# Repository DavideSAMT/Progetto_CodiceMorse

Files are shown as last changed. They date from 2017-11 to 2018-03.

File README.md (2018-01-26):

# Progetto_CodiceMorse

## Diari
 - [I3_Diario_Prog2_2017_11_10](Documentazione/Diari/I3_Diario_Prog2_2017_11_10.pdf)
 - [I3_Diario_Prog2_2017_11_17](Documentazione/Diari/I3_Diario_Prog2_2017_11_17.pdf)
 - [I3_Diario_Prog2_2017_11_22](Documentazione/Diari/I3_Diario_Prog2_2017_11_22.pdf)
 - [I3_Diario_Prog2_2017_12_01](Documentazione/Diari/I3_Diario_Prog2_2017_12_01.pdf)
 - [I3_Diario_Prog2_2017_12_15](Documentazione/Diari/I3_Diario_Prog2_2017_12_15.pdf)
 - [I3_Diario_Prog2_2017_12_22](Documentazione/Diari/I3_Diario_Prog2_2017_12_22.pdf)
 - [I3_Diario_Prog2_2018_01_12](Documentazione/Diari/I3_Diario_Prog2_2018_01_12.pdf)
 - [I3_Diario_Prog2_2018_01_19](Documentazione/Diari/I3_Diario_Prog2_2018_01_19.pdf)
 - [I3_Diario_Prog2_2018_01_26](Documentazione/Diari/I3_Diario_Prog2_2018_01_26.pdf)

## Documentazione
 - [Documentazione](Documentazione/Documentazione.doc)

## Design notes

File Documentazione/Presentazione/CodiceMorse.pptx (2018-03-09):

## Codice Morse

Federico agosta, Alessandro gomes, davide paradiso
e Patrick sartori

## Indice

- Analisi
- Progettazione
- Implementazione
- Test
- Conclusione

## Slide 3

Analisi

## Analisi – richiesta del mandante

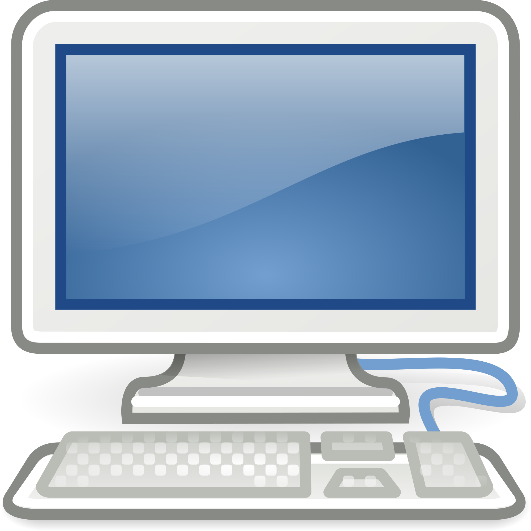
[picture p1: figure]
Risultati immagini per computer
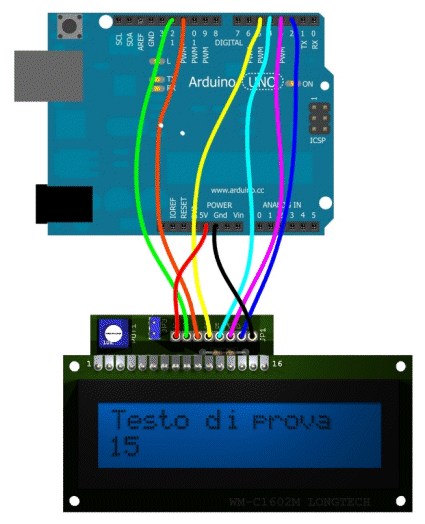
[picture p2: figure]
Risultati immagini per lcd

## Analisi – costi

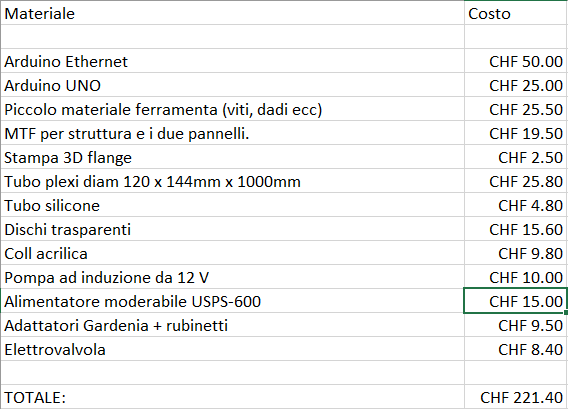
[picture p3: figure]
Analisi costi

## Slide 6

Progettazione

## Progettazione

Inserimento testo
Codifica
Salvataggio database, invio codice ad arduino
Azionamento elettrovalvola
Lettura frequenta e stampa su LCD

Bootstrap

PHP e JS

PHP

Arduino

## Progettazione pagina iniziale

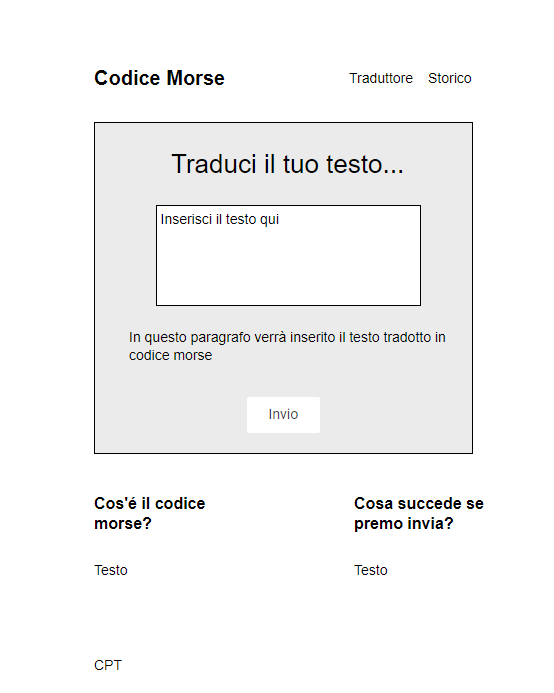
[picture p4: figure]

## Progettazione pagina storico

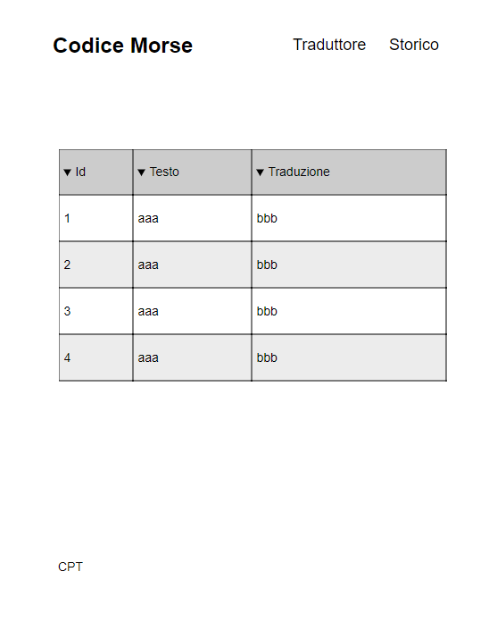
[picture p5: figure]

## Progettazione - database

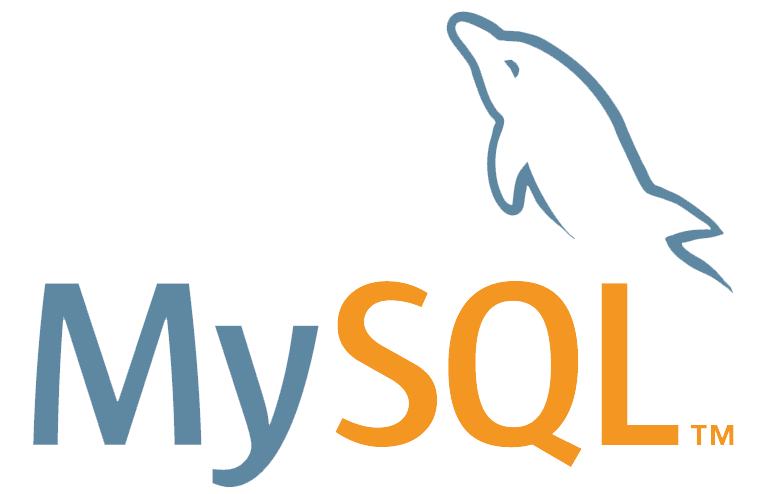
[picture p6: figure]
Risultati immagini per mysql
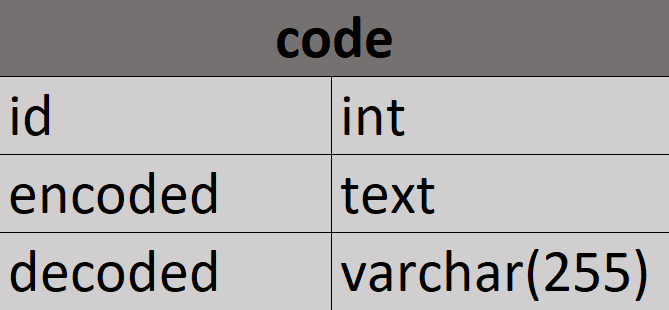
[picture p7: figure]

## Progettazione - elettrovalvola

- x1
- x3
- x7

## Progettazione - elettrovalvola

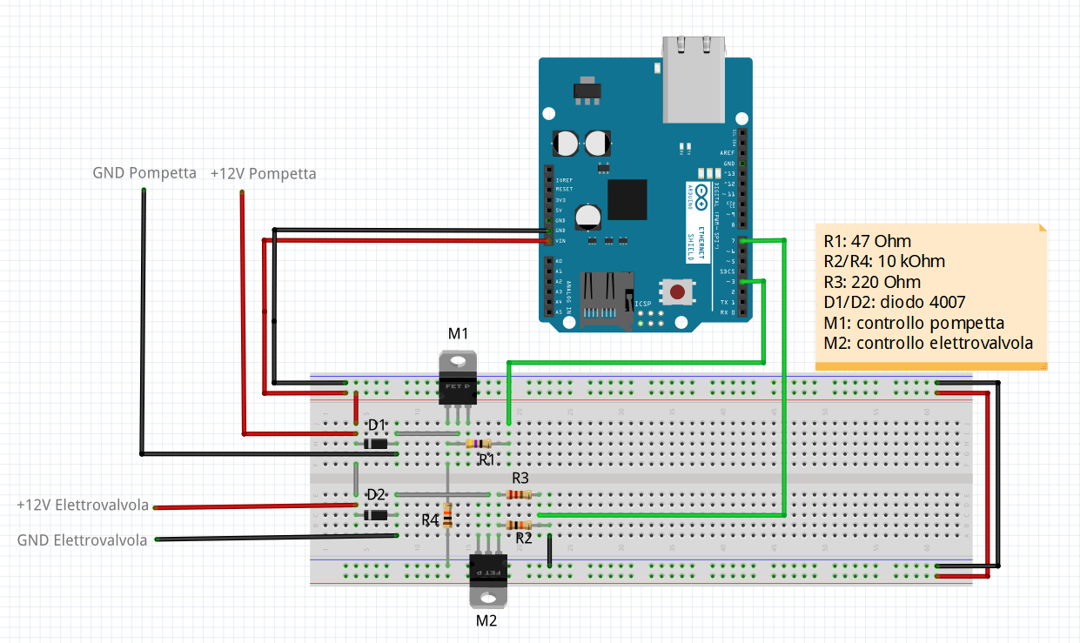
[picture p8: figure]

## Progettazione – sensore infrarossi

D

E

D

E

0

1

## Progettazione – sensore infrarossi

DOT

D

E

D

E

0

1

DASH

1111

1111111

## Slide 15

Il sensore legge un livello d’acqua insufficiente

Il sensore legge un livello d’acqua sufficiente

La pompa viene attivata

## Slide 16

Messaggio
Codificato con
Le gocce

Arduino

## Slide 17

Implementazione

## Implementazione pagina iniziale

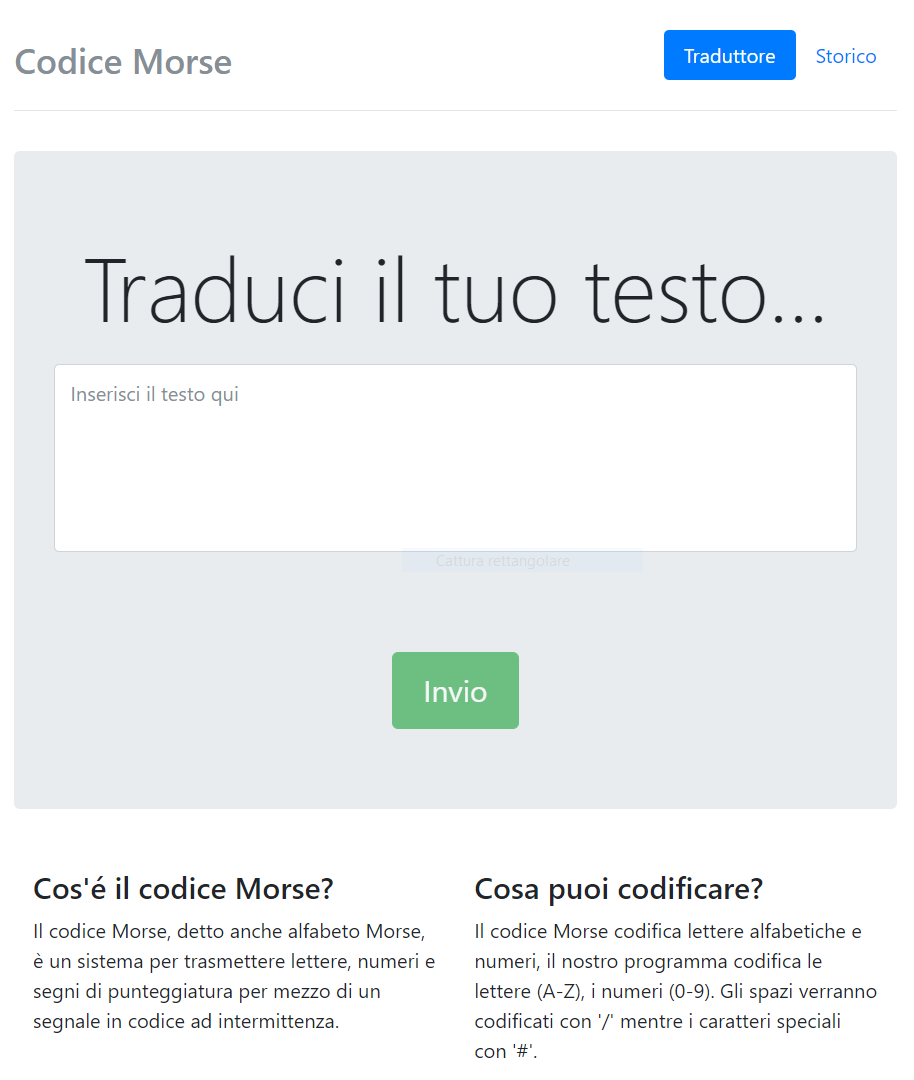
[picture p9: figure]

## Implementazione – pagina storico

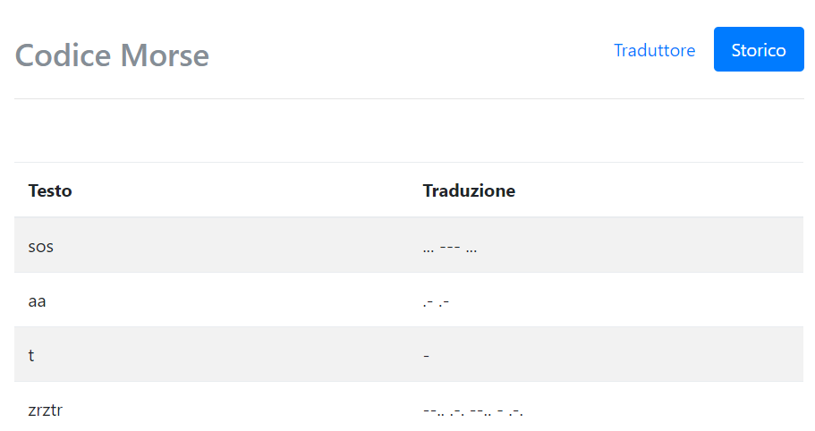
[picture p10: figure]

## Implementazione – pagina storico

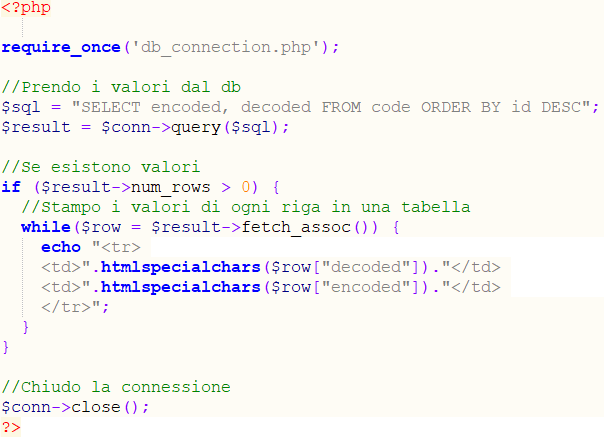
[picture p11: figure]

## Implementazione – controlli JS

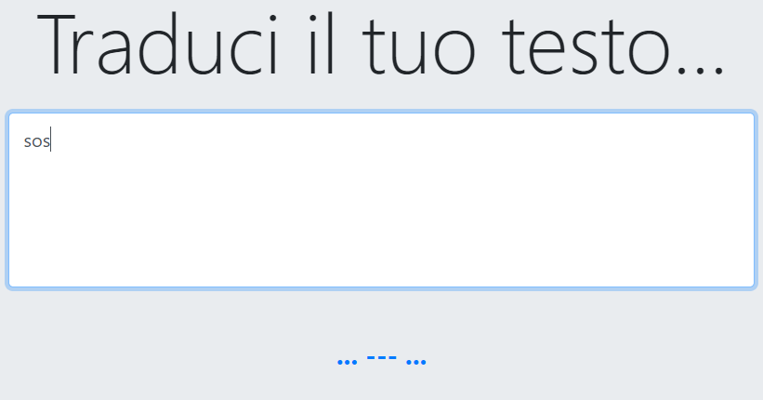
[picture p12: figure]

## Implementazione – controlli JS

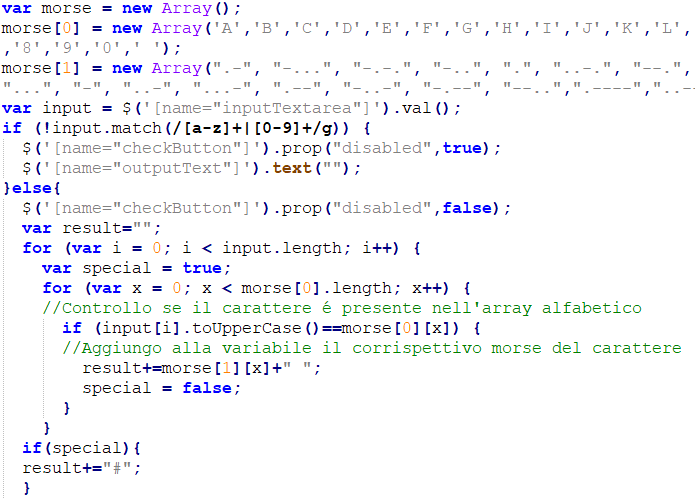
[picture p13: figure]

## Implementazione - elettrovalvola

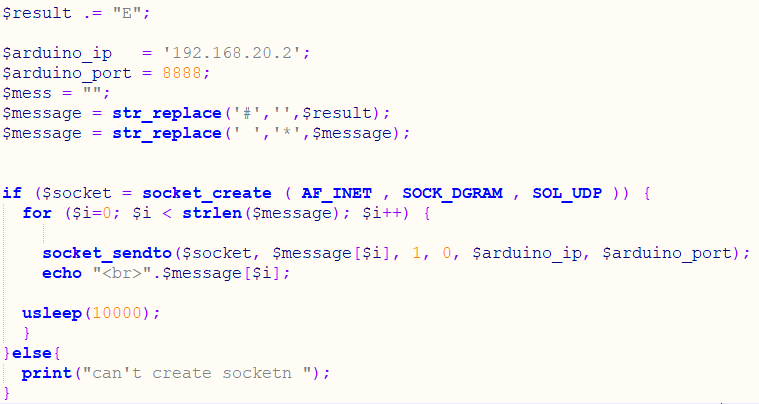
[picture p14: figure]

## Implementazione elettrovalvola

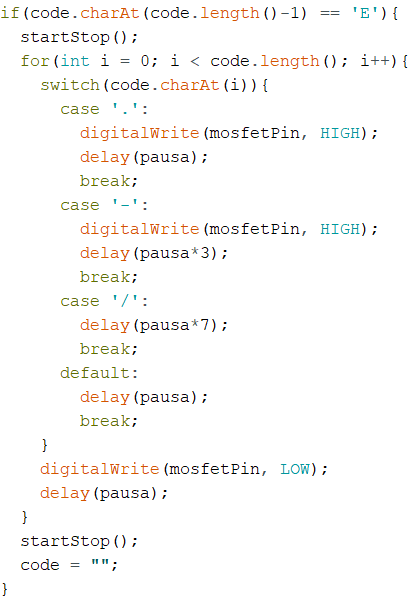
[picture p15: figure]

## Implementazione – pompetta e sensore

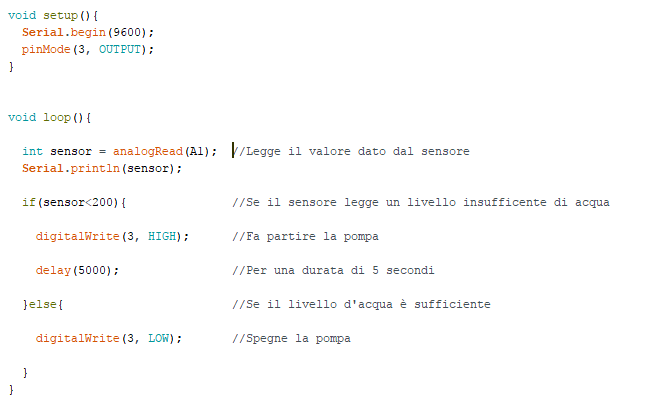
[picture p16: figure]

## Implementazione infrarossi

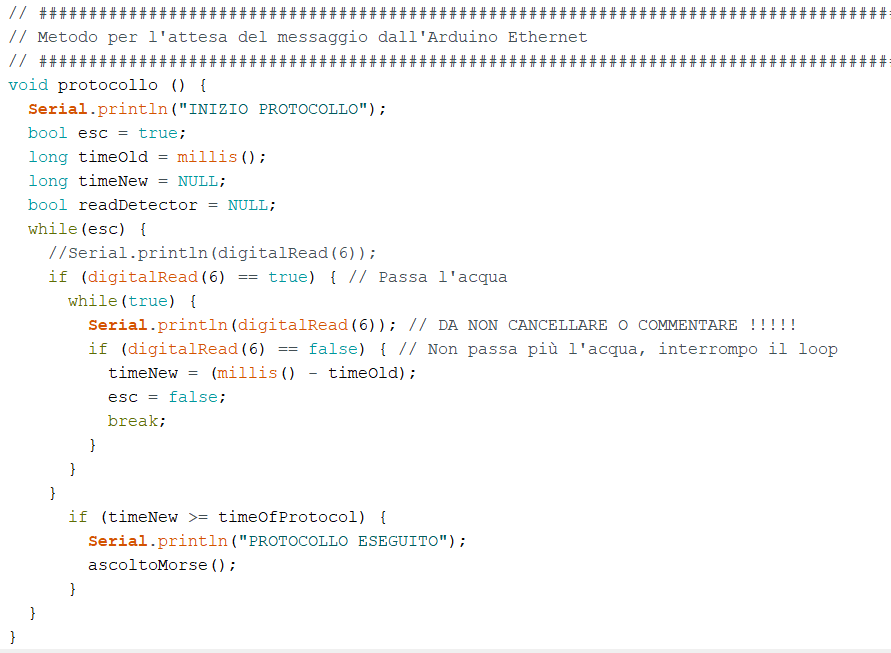
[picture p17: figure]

## Implementazione – sensore infrarossi

Goccia

No goccia

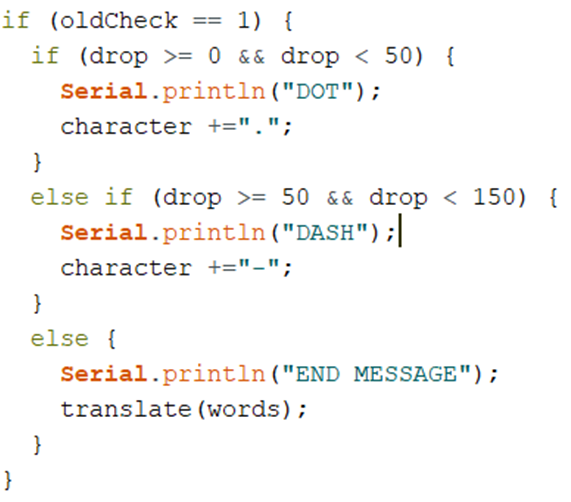
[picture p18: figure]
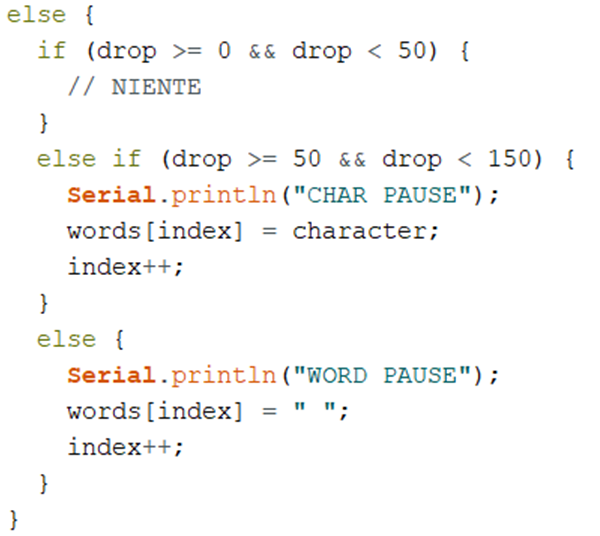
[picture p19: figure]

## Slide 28

Test

## Test

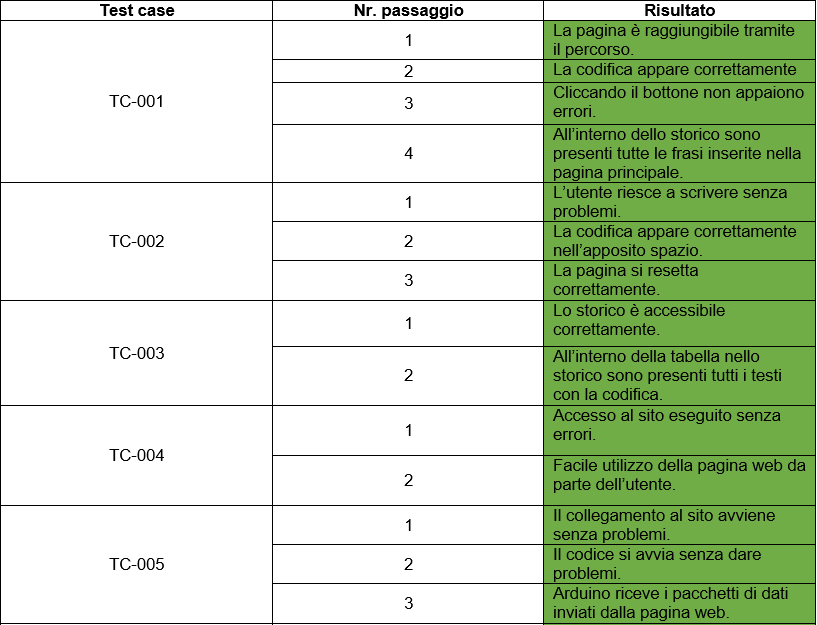
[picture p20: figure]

## Test

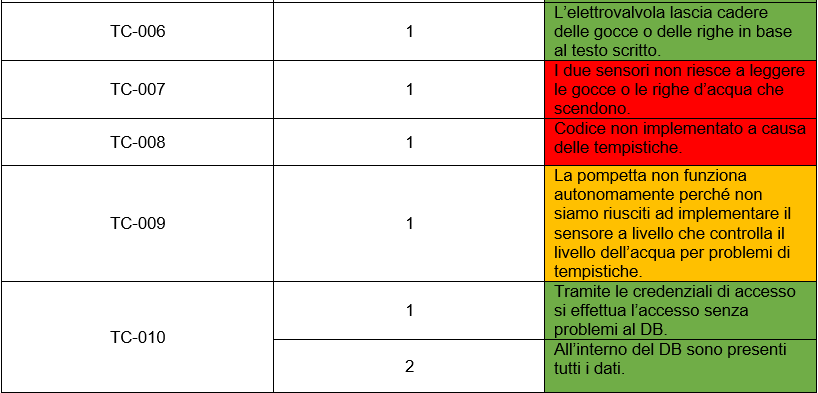
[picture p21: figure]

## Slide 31

Conclusioni

## Conclusioni

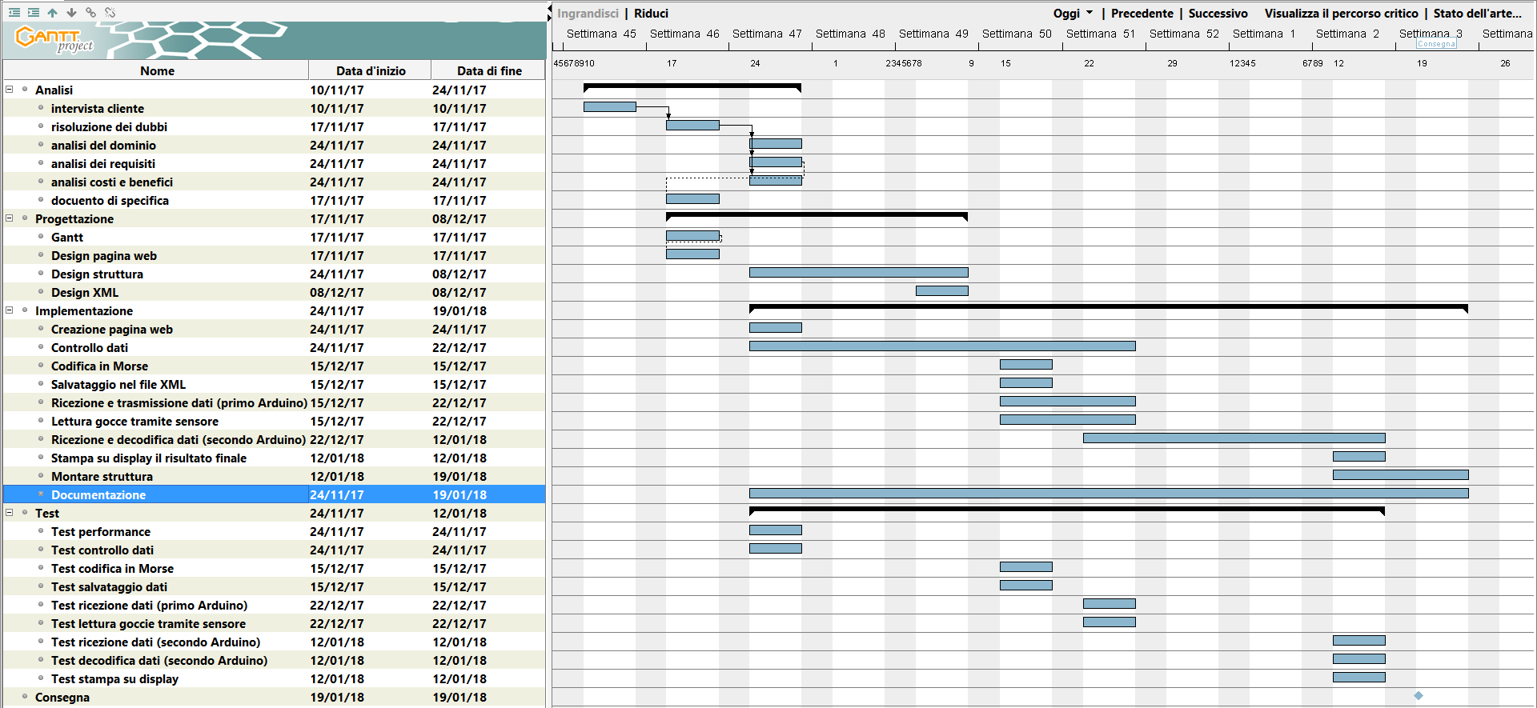
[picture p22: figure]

## Conclusioni

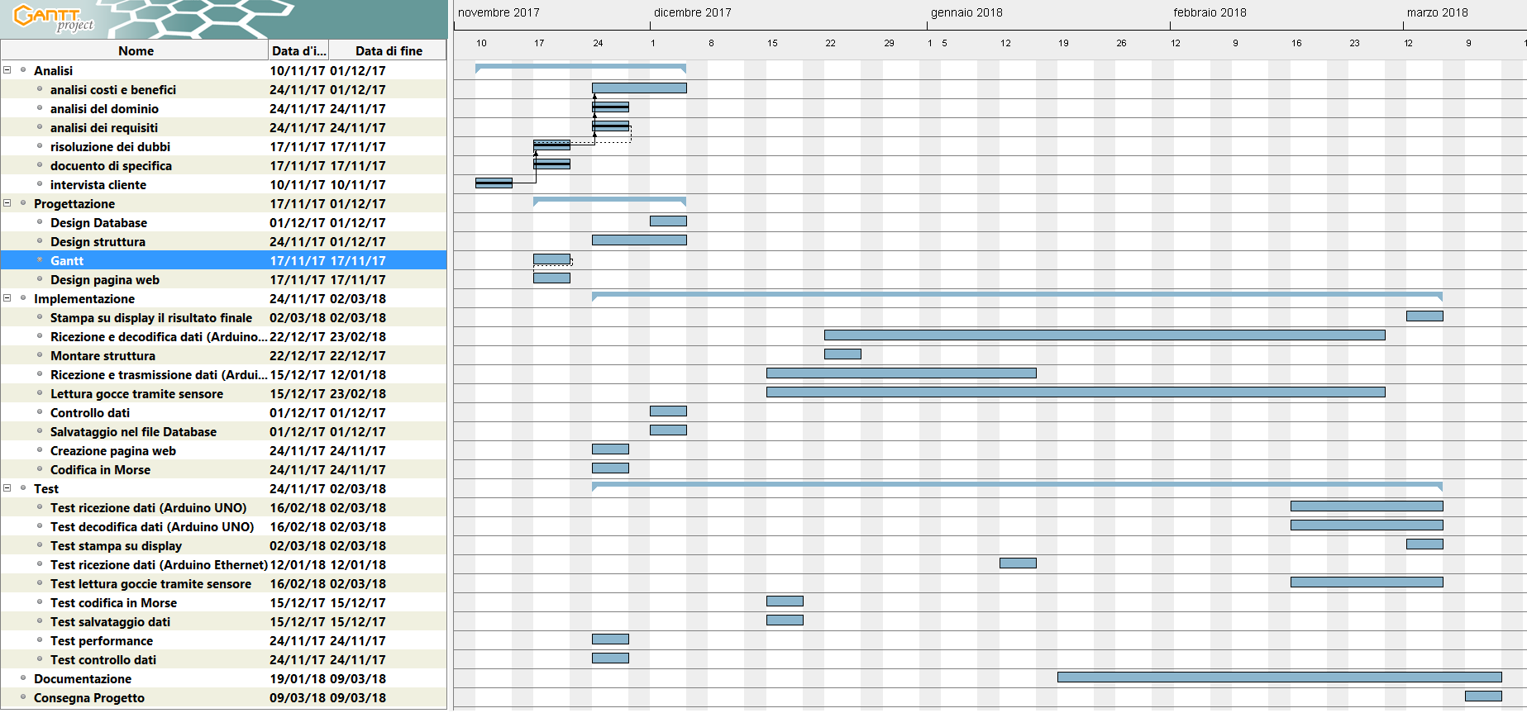
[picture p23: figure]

## Sviluppi futuri

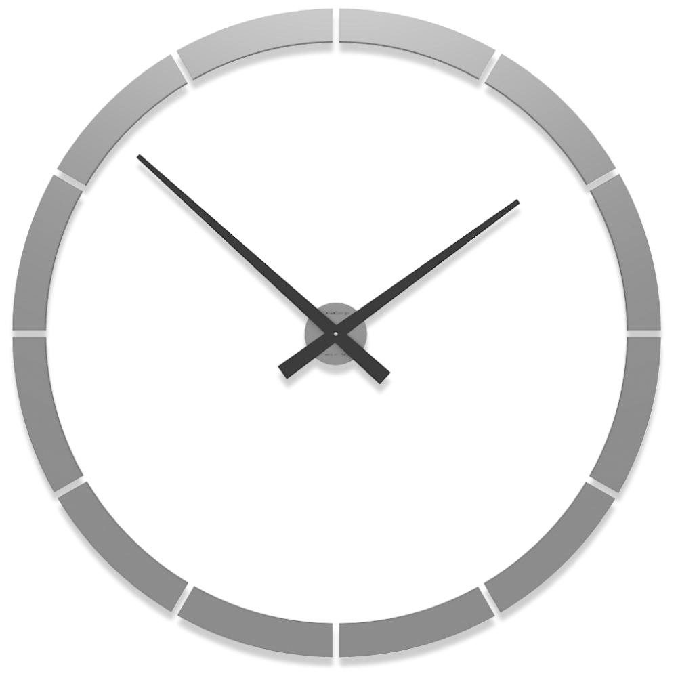
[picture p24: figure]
Risultati immagini per orologio

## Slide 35

Domande ?

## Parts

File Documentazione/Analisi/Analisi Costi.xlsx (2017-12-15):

Quantità | Materiale | Costo | Sito | ID
2 | Arduino/Genuino UNO | CHF 30.00
4 | Squadretta di fissaggio | CHF 5.55 | shop-da.dkh.ch | 10249209
16 | Viti per il legno 0.4 cm diametro | CHF 5.20
2 | Compensato 100 cm x 100 cm spessore 2.5 cm

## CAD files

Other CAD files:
Codice/ProgettoGraficoDavide.skp

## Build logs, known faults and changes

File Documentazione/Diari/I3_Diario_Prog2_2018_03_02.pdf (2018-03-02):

Davide Paradiso, Patrick Sartori, Alessandro Gomes

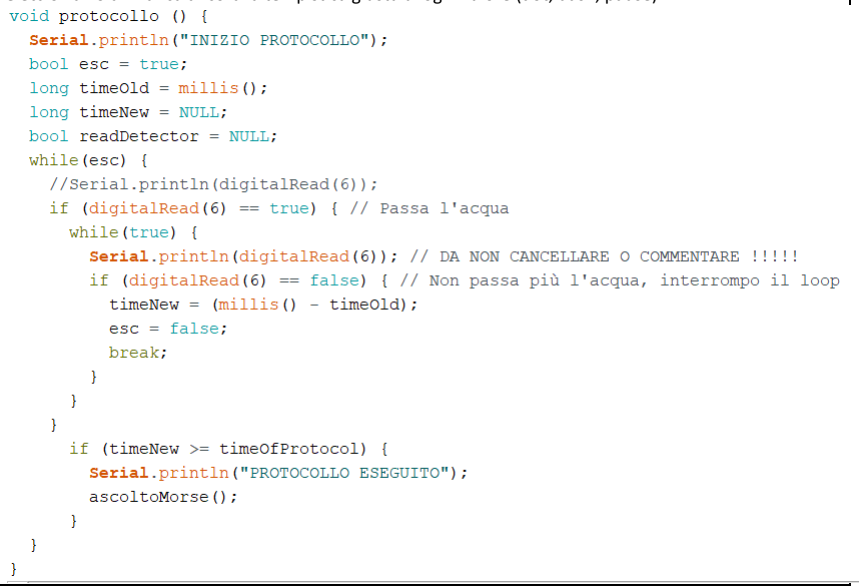
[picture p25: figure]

Nome Progetto: Codice Morse | 1/1

# Diario di lavoro

Luogo | Scuola Arti e Mestieri Trevano
Data | 02.03.18

Lavori svolti
Davide Paradiso:
Sono riuscito a concludere il codice sorgente della trasmissione a infrarossi abbastanza per testare con la elettro valvola. Manca ancora la tempistica giusta di ogni valore (dot, dash, pause).

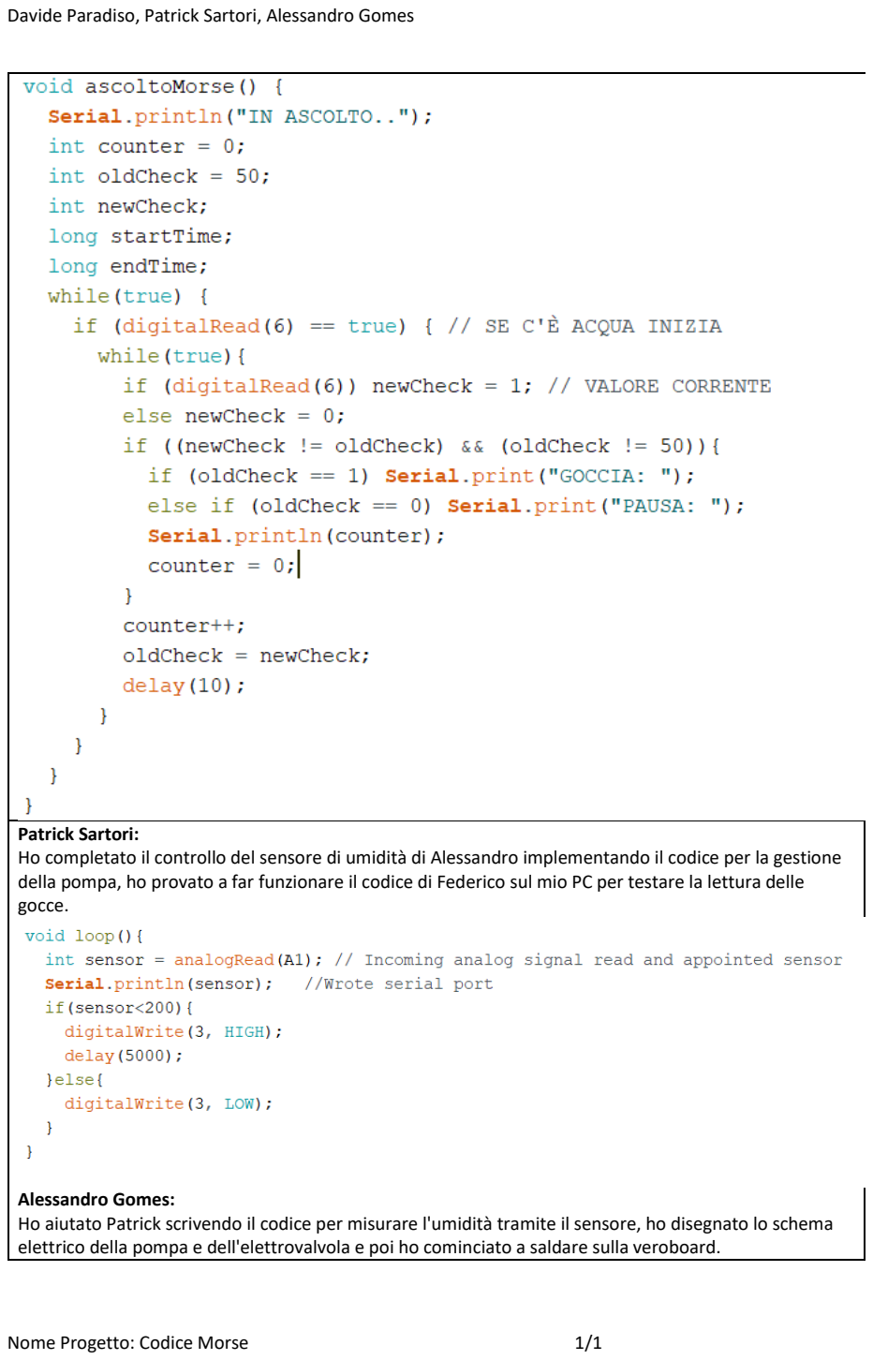
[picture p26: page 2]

Patrick Sartori:
Ho completato il controllo del sensore di umidità di Alessandro implementando il codice per la gestione della pompa, ho provato a far funzionare il codice di Federico sul mio PC per testare la lettura delle gocce.

Alessandro Gomes:
Ho aiutato Patrick scrivendo il codice per misurare l'umidità tramite il sensore, ho disegnato lo schema elettrico della pompa e dell'elettrovalvola e poi ho cominciato a saldare sulla veroboard.

Problemi riscontrati e soluzioni adottate
Davide Paradiso:
Ho riscontrato problemi con il codice sorgente ma grazie all’aiuto del professor Barchi sono riuscito a risolvere. Purtroppo non ho potuto testare perché la parte dell’elettro valvola che settimana scorsa andava, oggi sul pc di Patrick e sul mio non ha funzionato, abbiamo chiamato Federico al telefono svariate volte ma lui ha confermato che i codici erano giusti e il montaggio anche.
Patrick Sartori:
Non riuscivo a creare il socket, ho dovuto abilitare l'estensione per i socket in php.ini.
Alessandro Gomes:
Devo dissaldare una resistenza il PULL_DOWN perché l’ho messa male.

Punto della situazione rispetto alla pianificazione Progetto non concluso.

Programma di massima per la prossima giornata di lavoro

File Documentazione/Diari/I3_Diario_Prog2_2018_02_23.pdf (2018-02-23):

Davide Paradiso, Patrick Sartori, Federico Agosta, Alessandro Gomes

Progetto codice morse | 1/1

# Diario di lavoro

Luogo | SAMT
Data | 23.02.2018

Lavori svolti

Ho messo in rete la macchina con arduino sulla rete 200.200.200.1, poi ho eseguito una modifica del db e della query di creazione della struttura
perché ci siamo accorti che il range di varchar non basta per contenere la stringa di 255 caratteri codificata.
Invece di inviare spazi vuoti tra carattere e carattere ho introdotto il carattere * (Es: SOS -> ...*---*...*E), inoltre ho tolto lo switch
che controllava il tempo da PHP (pagina data_backup.php) perché lo gestisce Arduino (valvola.ino).
Ho aggiunto il codice Arduino che gestisce l'elettrovalvola collegata alla pagina PHP, in modo che quando viene inviato un messaggio l'elettrovalvola
stampa il risultato in codice morse corretto e con le tempistiche giuste, in caso che si invii un nuovo messaggio durante l'elaborazione il messaggio verrà
archiviato e eseguito appena possibile.

Oggi sono riuscito a far funzionare la pompa, i problemi erano:
Il mosfet danneggiato,
Gli ingranaggi non oliati,
La resistenza di controllo del mosfet era troppo alta.

Problemi riscontrati e soluzioni adottate

Ho sostituito il mosfet,

Ho oliato gli ingranaggi del motore,

Ho sostituito la resisteza di controllo con una resistenza da 47 Ohm.

Programma di massima per la prossima giornata di lavoro

La prossima lezione devo controllare che la query funzioni e controllare la riga 64 di valvola.ino se é superflua o meno.

Davide Paradiso, Patrick Sartori, Federico Agosta, Alessandro Gomes

Progetto codice morse | 1/1

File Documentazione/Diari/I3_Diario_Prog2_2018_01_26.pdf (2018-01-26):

Davide Paradiso, Patrick Sartori, Federico Agosta, Alessandro Gomes

# Diario di lavoro

Luogo | SAMT
Data | 26.01.2018

Lavori svolti

Inizialmente abbiamo sistemato la struttura delle cartelle su github e aggiunto le informazione all'interno del readme.md iniziale.
Successivamente abbiamo dovuto modificare il codice della valvola di arduino in modo che sia arduino a gestire i tempi di attesa tra un punto e l'altro e non php, abbiamo dovuto di
conseguenza modificare anche il codice di php che gestiva il tempo, inoltre abbiamo aggiunto un carattere "E" per segnalare la fine del messaggio in modo che dopo
arduino possa ripulire la variabile. Una volta terminato il lavoro abbiamo cominciato con il testare la elettro valvola per poterla implementare
all'interno del codice di arduino "valvola.ino", dato che il voltaggio del arduino é troppo debole per poter alimentare l'elettro valvola
ci è stato dato un Mosfet "IRF520" che può distribuire fino a 100V e 9,2A, per l'elettro valvola basta un voltaggio di 12V e 250mA.
Le informazioni le abbiamo prese da "https://www.vishay.com/docs/91017/91017.pdf".
Inoltre abbiamo cominciato il montaggio della struttura con le misure corrette e il materiale adeguato, prima di cominciare abbiamo ottenuto l’accordo da parte dei docenti responsabili dato che non abbiamo cambi in caso di errore.

Problemi riscontrati e soluzioni adottate

Capire come funziona il Mosfet e riuscire a tesarlo insieme all’ elettro valvola in modo che funzionasse. Per il montaggio bisognava aspettare il docente responsabile che supervisionasse che non sempre era disponibile.

Punto della situazione rispetto alla pianificazione

In confronto alla pianificazione avremmo già dovuto finire, ma se la consegna è espoprofessioni siamo a buon punto.

Programma di massima per la prossima giornata di lavoro

Terminare il funzionamento dell’elettro valvola funzionante e terminare il montaggio rude della struttura (pittura e abbellimenti verranno effettuati in seguito). Poi ci rimarrà solamente da leggere le gocce e stampare sul display LCD.

Progetto codice morse | 1/1

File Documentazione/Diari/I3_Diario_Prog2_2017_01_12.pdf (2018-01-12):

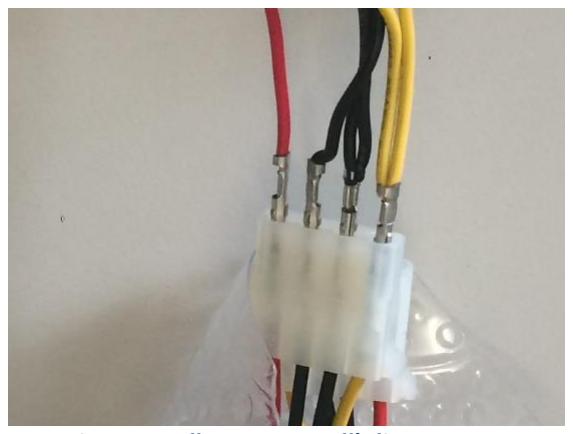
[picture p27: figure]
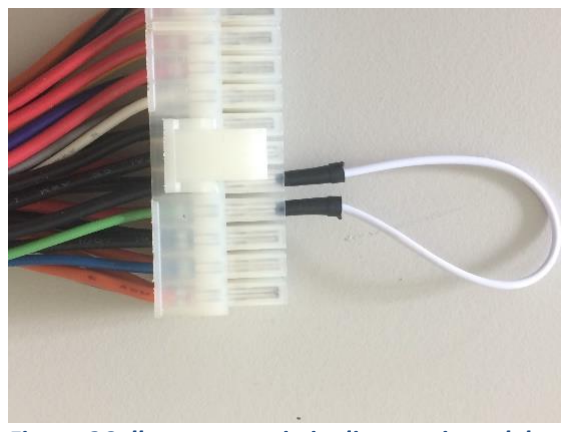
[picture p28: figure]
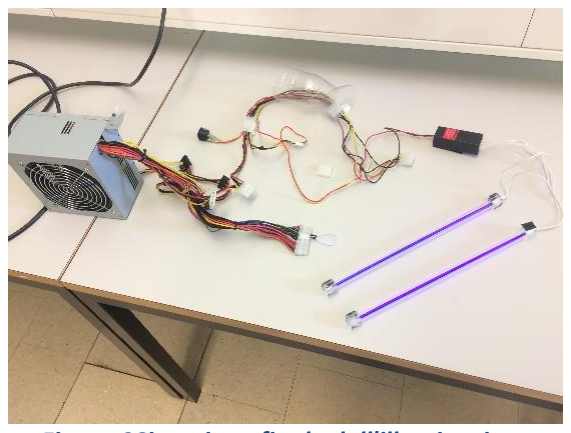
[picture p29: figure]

Nome Progetto: Codice Morse | 1/1

# Diario di lavoro

Luogo | Scuola Arti e Mestieri Trevano
Data | 12.01.2018

Lavori svolti
Davide:
A inizio lezione ho preso le misure per il fissaggio dei componenti sull’infrastruttura. Prima di pranzo ho fatto funzionare il sistema di illuminazione per l’acqua.

Figura 1Collegamento all'alimentatore

Figura 2Collegamento ai pin di accensione del pc

Figura 3Situazione finale dell'illuminazione

Dopo pranzo ho iniziato a simulare la comunicazione tra due arduini e l’invio di un codice morse.

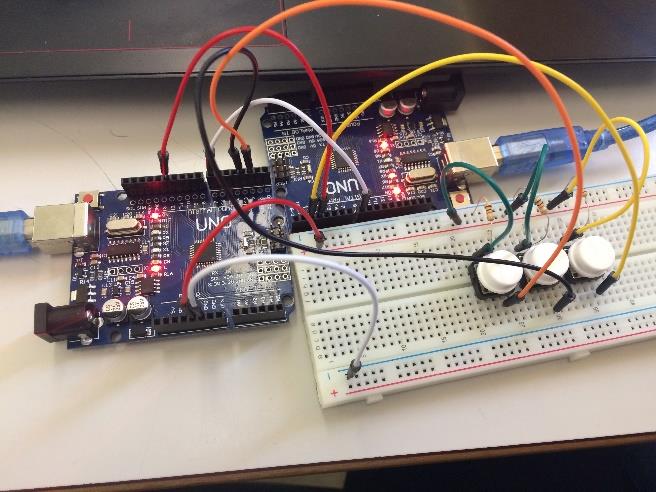
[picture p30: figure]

L’immagine seguente è il codice dell’Arduino che simula la scrittura del morse e manda il messaggio al secondo Arduino.

Federico:

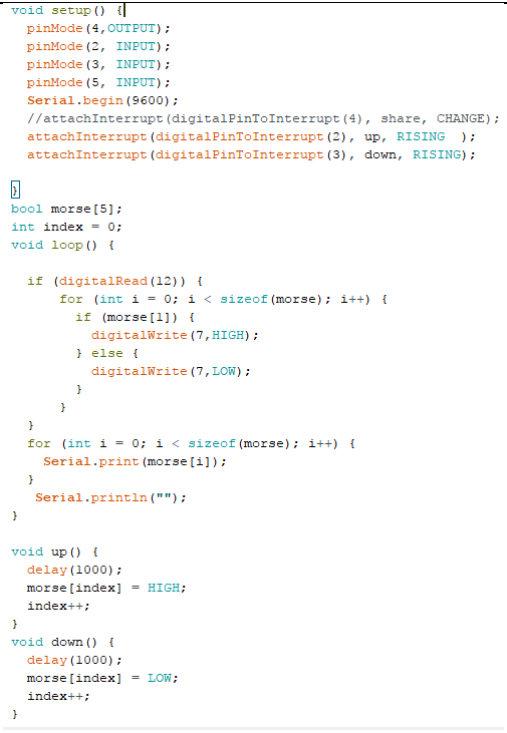
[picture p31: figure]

Ho cercato un metodo per inviare i dati da PHP a d Arduino, ho trovato un sistema che potrebbe fare al caso nostro all'indirizzo https://www.arduino.cc/en/Tutorial/UDPSendReceiveString
usando UDPSendReceiveString di é possibile tenere Arduino in ascolto su una porta a nostra scelta, per poter testare se funziona abbiamo bisogno della libreria EthernetUdp.h di Arduino.
Nelle impostazioni di php.ini ho dovuto abilitare i socket di php, l'inforamzione l'ho trovata grazie all'errore https://stackoverflow.com/questions/6137823/fatal-error-call-to-undefined-function-socket-create
Una volta inviati i dati abbiamo dovuto aumentare il tempo di esecuzione da php.ini, ho deciso di inviare un carattere alla volta per poter rispettare il massimo di 24byte massimi del protocollo udp e con lo sleep si può fare in modo di aprire e chiudere direttamente la elettro valvola. Per poter aggiungere tesmpo ho aggiunto
$cfg['ExecTimeLimit'] = 6000; in config.inc.php e max_execution_time in php.ini.

Patrick:
Durante questa lezione mi sono occupato di creare il codice di arduino per leggere il codice inviato tramite dei bottoni.

void setup() {
pinMode(8, INPUT);
pinMode(2, INPUT);
Serial.begin(9600);
attachInterrupt(digitalPinToInterrupt(2), invio,RISING);

}
bool ciao[5];
void invio(){
digitalWrite(3, HIGH);
for(int i =0;i<sizeof(ciao); i++){ ciao[i] = digitalRead(8);
}
}

String s1;
void loop() {
//s1=ciao[0]+ciao[1]+ciao[2]+ciao[3]+ciao[4]; for(int i =0;i<sizeof(ciao); i++){
delay(5);
Serial.print(ciao[i]);
}

/* String morse[] = {".-", "-...", "-.-.", "-..", ".", "..-.", "--.", "....", "..", ".---", "-.-", ".-..", "--", "-.", "---", ".--.", "--.-", ".-.", "...", "-", "..-", "...-", ".--", "-..-", "-.--", "--..",".----","..---","...--","....-",".....","-....","--...","---..","----.","-----", "/"};
char
alfa[]={'A','B','C','D','E','F','G','H','I','J','K','L','M','N','O','P','Q','R','S','T','U','V','W','X','Y','Z','1','2','3','4','5','6',' 7','8','9','0',' '};
for(int i = 0; i<sizeof(morse);i++){
if(s1==morse[i]){
s1=alfa[i];
}
}
for(int i = 0; i<sizeof(morse);i++){ if(s2==morse[i]){
s2=alfa[i];
}
}
for(int i = 0; i<sizeof(morse);i++){ if(s3==morse[i]){
s3=alfa[i];
}

}*/
Serial.println();
}

Problemi riscontrati e soluzioni adottate
I due Arduini leggono e scrivono troppo velocemente e anche avendo usato gli interrupt non sono sincronizzati.
Purtroppo il problema persiste ancora.
Il codice legge solo i codici “…..” (“11111”) e “-----” (“00000”), non abbiamo trovato una soluzione ma abbiamo delle supposizioni ovvero:
1. O l’arduino che invia manda il messaggio troppo velocemente oppure l’arduino che riceve legge il messaggio troppo velocemente.
Viene considerato il primo indice dell’array e viene stampato solo quello.

Punto della situazione rispetto alla pianificazione In ritardo rispetto alla pianificazione iniziale

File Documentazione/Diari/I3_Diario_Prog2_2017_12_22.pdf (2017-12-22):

Federico Agosta, Alessandro Gomes, Davide Paradiso e Patrick Sartori

# Diario di lavoro

Luogo | Scuola Arti e Mestieri Trevano
Data | 22.12.2017

Lavori svolti
Federico Agosta:
Ho cambiato l’IP del mio computer che lo usiamo come server in 200.200.200.1 (ip statico), poi ho rimosso il proxy e attivato xampp, in questo modo il computer è pronto per lavorare.
Appena cominciato a lavorare si è risolto da solo il problema della connessione tra arduino e il nostro server, probabilmente la soluzione è stata nello spegnere e riaccendere il pc.
Poi abbiamo cominciato ad informarci su come inviare delle variabili da PHP ad arduino dato che le nostre conoscenze su questi linguaggi sono scarse. Abbiamo usufruito della guida ufficiale di arduino per capire meglio il funzionamento del prodotto, soprattutto su come utilizzare i socket.
Ho cominciato a fare dei test per capire e verificare il funzionamento dei socket dato che non gli ho mai utilizzati.
Ho preso il codice da arduino.cc per fare in modo che il nostro ArduinoEthernet sia in ascolto su una porta e riceva dei messaggi.

Alessandro Gomes:
Ho rimosso il proxy perché la scuola ha problemi con la rete e di conseguenza mi sono dovuto collegare alla mia rete internet personale tramite il mio telefono.
Subito dopo ho cominciato a fare ricerche per aiutare il mio compagno Federico a risolvere il problema del collegamento tra l’arduino e il computer, una volta risolto ho cominciato a fare altre ricerche per aiutare il mio collega di progetto nel collegamento tra l’arduino e la pagine web. In seguito ho dovuto modificare diversi capitoli della documentazione e anche aggiungere nel Gantt il tempo per la documentazione.

Davide Paradiso:
Ho fatto diverse prova per la lettura delle gocce, sia con il lettore d’infrarossi che con il lettore laser. Alla fine per motivi organizzativi e per ordine del sore ho insistito con la lettura tramite infrarossi. Il lettore laser era troppo impreciso e al minimo spostamento non leggeva più il segnale.
La versione finale del codice sorgente che sto utilizzando è il seguente:

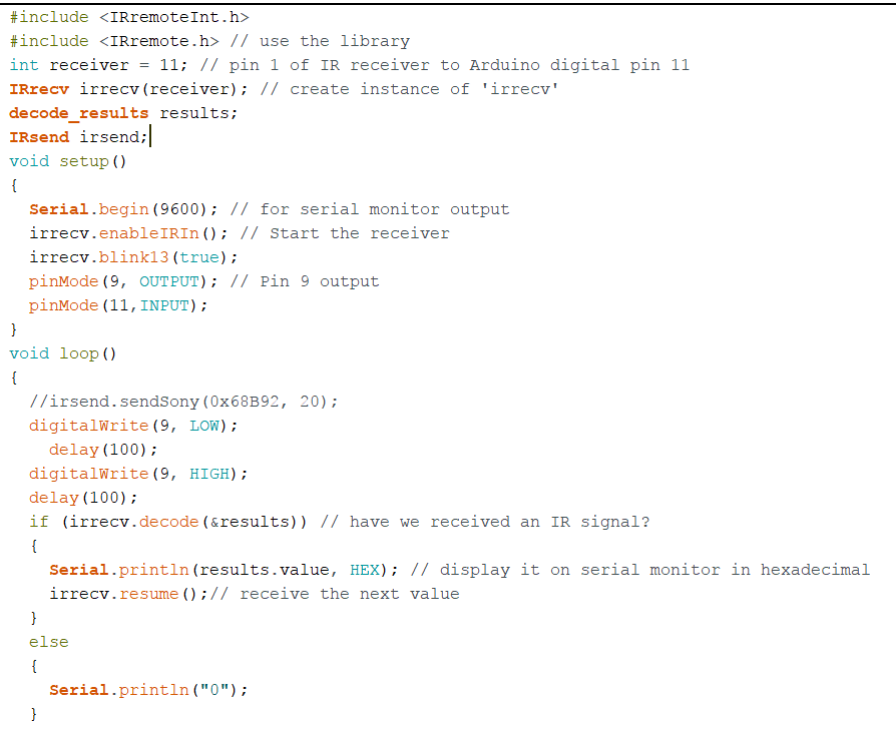
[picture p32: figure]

Appena saprò con certezza i pezzi giusti da usare pubblicherò i loro data sheets su GitHub.

Patrick Sartori:
Ho aggiornato il gantt consuntivo, ho cercato il modello del led a infrarossi per poi cercare il datasheet, il modello di led a infrarossi che usiamo è lo TSUS 5402.

Problemi riscontrati e soluzioni adottate
Alle 10.20 abbiamo avuto bisogno di internet ma la rete scolastica non funzionava, abbiamo dovuto attendere che risolvessero il problema, intento abbiamo usato il nostro internet fornito dai telefoni cellulari.
L’attuatore ad infrarossi non ha la stessa frequenza del sensore di lettura, l’ho verificato leggendo i data sheets di entrambi i pezzi, quindi poi ho cercato un attuatore compatibile.
Essendo che il nostro attuatore e il nostro ricevitore non sono compatibili ho cercato un altro attuatore compatibile e l’attuatore che ho trovato è l’IR333-A, sito del datasheet: https://docs.particle.io/assets/datasheets/makerkit/ir333-a.pdf

Punto della situazione rispetto alla pianificazione Leggermente indietro confronto alla pianificazione

Programma di massima per la prossima giornata di lavoro
Per le vacanze devo trovare una soluzione e comunicarla al sore. (Davide)

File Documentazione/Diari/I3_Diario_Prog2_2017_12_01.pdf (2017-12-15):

Davide Paradiso, Patrick Sartori, Federico Agosta, Alessandro Gomes

Progetto codice morse | 1/1

# Diario di lavoro

Luogo | SAMT
Data | 1.12.2017

Lavori svolti

Oggi abbiamo iniziato a fare l’analisi dei costi, abbiamo finito il file php per creare lo storico dei messaggi, abbiamo completato l’abstract, abbiamo iniziato a vedere come funzionano il led a infrarossi e il ricevitore a infrarossi, abbiamo provato a connettere l’arduino alla pagina web tramite un cavo ethernet, abbiamo aggiornato il gantt perché ci siamo dimenticati di includere il ponte, abbiamo bloccato la possibilità di ispezionare gli elementi in HTML e infine abbiamo finito lo schema grafico della struttura.

Problemi riscontrati e soluzioni adottate

Non siamo riusciti a trovare un cavo d’alimentazione per l’arduino, non riuscivamo a trovare il driver giusto per arduino, lo abbiamo risolto trovando il driver CH341SER, abbiamo avuto infine un ultimo problema con la formattazione del testo nelle tabelle che abbiamo poi risolto con il css usando nel tag table lo style=”table-layout:fixed”, e per il td lo sstyle=”word-wrap:break-word”.

Punto della situazione rispetto alla pianificazione

Siamo leggermente in anticipo.

Programma di massima per la prossima giornata di lavoro

Iniziare a programmare in arduino.
Modifica requisiti,

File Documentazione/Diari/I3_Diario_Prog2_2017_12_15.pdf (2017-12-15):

Davide Paradiso, Patrick Sartori, Federico Agosta, Alessandro Gomes

Progetto codice morse | 1/1

# Diario di lavoro

Luogo | SAMT
Data | 15.12.2017

Lavori svolti

Oggi abbiamo iniziato a programmare in arduino, siamo riusciti a far funzionare il ricevitore a infrarossi, stiamo iniziando a mandare i dati dalla pagina php all’arduino, abbiamo quasi ultimato l’analisi dei costi, abbiamo trovato e risolto un errore nel salvataggio dei dati nella tabella.

Problemi riscontrati e soluzioni adottate

Abbiamo riscontrato problemi con le librerie a infrarossi di arduino, con il led a infrarossi, con la connessione di arduino ethernet al computer.

Abbiamo risolto i problemi di libreria scaricando la stessa libreria di nuovo e i problemi di connessione di arduino ethernet cambiando l’adattatore ad arduino.

Punto della situazione rispetto alla pianificazione

Siamo in orario.

Programma di massima per la prossima giornata di lavoro

Finire la programmazione in arduino.
Far funzionare la lan di arduino.

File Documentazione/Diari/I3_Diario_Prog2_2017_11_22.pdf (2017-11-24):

Davide Paradiso, Patrick Sartori, Federico Agosta, Alessandro Gomes

Nome Progetto: Form di inserimento dati Espoprofessioni | 1/1

# Diario di lavoro

Luogo | Scuola Arti e Mestieri Trevano
Data | 24.11.2017

Lavori svolti
Abbiamo concluso la parte di analisi a parte la sezione dei costi, l’abstract, il gantt preventivo, abbiamo iniziato a progettare la struttura e fare l’elenco dei materiali.
Abbiamo aggiornato la documentazione.
Design della pagina web concluso e lo script che traduce l’italiano in morse.

Problemi riscontrati e soluzioni adottate

Punto della situazione rispetto alla pianificazione Più o meno in orario.

Programma di massima per la prossima giornata di lavoro Finire PHP e iniziare con Arduino.

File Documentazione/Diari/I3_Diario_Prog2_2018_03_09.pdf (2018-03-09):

Davide Paradiso, Patrick Sartori, Federico Agosta, Alessandro Gomes

Progetto codice morse | 1/1

# Diario di lavoro

Luogo | SAMT
Data | 09.03.2018

Lavori svolti

Oggi ci siamo dedicati a fare la documentazione e la presentazione.

Problemi riscontrati e soluzioni adottate

Punto della situazione rispetto alla pianificazione

Programma di massima per la prossima giornata di lavoro

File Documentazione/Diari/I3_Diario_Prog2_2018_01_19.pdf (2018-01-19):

Davide Paradiso, Patrick Sartori, Federico Agosta, Alessandro Gomes

Progetto codice morse | 1/1

# Diario di lavoro

Luogo | SAMT
Data | 19.01.2018

Lavori svolti

Durante la lezione di oggi ci siamo divisi in due gruppi, uno gruppo che si occupava di fare la documentazione e un gruppo che si occupava di fare la presentazione.
Federico si è occupato di aggiornare il trello e di sistemare il codice di arduino ethernet, Davide ha cominciato ad utilizzare il display LCD, Alessandro e Patrick hanno fatto gli ultimi elementi della documentazione mancanti, ovvero l’implementazione, i test case, il consuntivo, le conclusioni e il gantt consuntivo.

Problemi riscontrati e soluzioni adottate

Punto della situazione rispetto alla pianificazione

Consegna

Programma di massima per la prossima giornata di lavoro

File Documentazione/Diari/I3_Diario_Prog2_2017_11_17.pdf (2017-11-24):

Nome Progetto: | 1/1

# Diario di lavoro

Luogo | SAM Trevano
Data | 17.11.2017

Lavori svolti
Abbiamo fatto il colloquio con il docente responsabile, nel quale abbiamo risolto i nostri dubbi legati al mandato. Abbiamo cominciato a scrivere i requisiti per poi dividerci i compiti. Con trello abbiamo cominciato a scrivere i requisiti per poi gestirli meglio. Abbiamo cominciato con la documentazione del progetto.

Problemi riscontrati e soluzioni adottate
Nessun problema riscontrato

Punto della situazione rispetto alla pianificazione Stiamo ancora pianificando

Programma di massima per la prossima giornata di lavoro

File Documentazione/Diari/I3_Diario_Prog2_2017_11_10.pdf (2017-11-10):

Davide Paradiso, Patrick Sartori, Federico Agosta, Alessandro Gomes

Nome Progetto: Form di inserimento dati Espoprofessioni | 1/1

# Diario di lavoro

Luogo | Scuola Arti e Mestieri Trevano
Data | 10.11.2017

Lavori svolti
Abbiamo creato la Repository del progetto su Github e abbiamo iniziato a fare l’analisi dei requisiti. Abbiamo guardato il progetto di riferimento per darci un idea su come verrà.

Problemi riscontrati e soluzioni adottate

Punto della situazione rispetto alla pianificazione Più o meno in orario.

Programma di massima per la prossima giornata di lavoro

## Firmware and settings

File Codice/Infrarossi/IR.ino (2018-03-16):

int X;
#define emitter 5
#define detector 6
#define tester 8
int timer1_counter;
// VARIABILI MORSE VALORI STANDARD
// *******************************
int dot = 1;
int symbolSpace = dot;
int dash = dot * 3;
int letterSpace = dash;
int wordSpace = dot * 7;
// *******************************
int timeOfProtocol = 10; // MILLI_SECONDI
void setup() {
  pinMode(emitter, OUTPUT);
  pinMode(detector, INPUT);
  Serial.begin(9600);
  
  //inizialize Timer
  noInterrupts();           // Disabilito tutti gli interrupts
  TCCR1A = 0;               // TCCR1A, costante già esistente in Arduino
  TCCR1B = 0;               // TCCR1B, costante già esistente in Arduino
  timer1_counter = 65534;   // timer1_counter, variabile che rappresenta la frequenza
  TCNT1 = timer1_counter;   // TCNT1, costante già esistente in Arduino
  TCCR1B |= (1 << CS12);
  TIMSK1 |= (1 << TOIE1);
  interrupts();             // Riattivo tutti gli interrupts
}
// Frequenza dell'emitter
bool frequencyE;
// Frequenza del detector
bool frequencyD;
ISR(TIMER1_OVF_vect) {
  TCNT1 = timer1_counter;
  // Imposto la frequenza dell'emitter IR
  digitalWrite(emitter, digitalRead(emitter) ^ 1);
  // EMITTER FREQUENCY
  frequencyE = (digitalRead(emitter) ^ 1);
  // DETECTOR FREQUENCY
  frequencyD = digitalRead(detector);
}
String words; // Parole 
// #####################################################################################################################################################################################
// METODO PRINCIPALE
// #####################################################################################################################################################################################
void loop() {
  Serial.println("INIZIO");
  protocollo();
}
// #####################################################################################################################################################################################
// Metodo che traduce il messaggio in codice morse ricevuto in una stringa in italiano
// #####################################################################################################################################################################################
void translate(String str[]) {
  String result = "";
  String morse[] = {
                    ".-", "-...", "-.-.", "-..", ".", "..-.", "--.", "....", "..", 
                    ".---", "-.-", ".-..", "--", "-.", "---", ".--.", "--.-", ".-.", 
                    "...", "-", "..-", "...-", ".--", "-..-", "-.--", "--..",".----",
                    "..---","...--","....-",".....","-....","--...","---..","----.",
                    "-----", "/"
                    };
  char alfa[]={
               'A','B','C','D','E','F','G','H','I','J','K','L','M','N',
               'O','P','Q','R','S','T','U','V','W','X','Y','Z','1','2',
               '3','4','5','6','7','8','9','0',' '
               };
  for (int i = 0; i < 255; i++) {
    for(int j = 0; j < 37; j++) {
      if(str[i] == morse[j]) {
        result += alfa[j];
      }
    }
  }
  return result; // STAMPA IL RISULTATO IN ITALIANO SUL LCD
}
// #####################################################################################################################################################################################
// Metodo per l'attesa del messaggio dall'Arduino Ethernet
// #####################################################################################################################################################################################
void protocollo () { 
  Serial.println("INIZIO PROTOCOLLO");
  bool esc = true;
  long timeOld = millis();
  long timeNew = NULL;
  bool readDetector = NULL;
  while(esc) {
    //Serial.println(digitalRead(6));
    if (digitalRead(6) == true) { // Passa l'acqua 
      while(true) {
        Serial.println(digitalRead(6)); // DA NON CANCELLARE O COMMENTARE !!!!!
        if (digitalRead(6) == false) { // Non passa più l'acqua, interrompo il loop
          timeNew = (millis() - timeOld);
          esc = false;
          break;
        }
      }
    }
      if (timeNew >= timeOfProtocol) {
        Serial.println("PROTOCOLLO ESEGUITO");
        ascoltoMorse();
      } 
  }
}
// #####################################################################################################################################################################################
// Metodo che attende il messaggio dall'elettrovalvola e lo memorizza
// #####################################################################################################################################################################################
void ascoltoMorse() {
  Serial.println("IN ASCOLTO..");
  //###-VARIABILI-##############################################################
  String character = "";              // CARATTERE ALFABETICO ESPRESSO IN MORSE
  String words[255];                  // CARATTERI DA TRADURRE
  int index = 0;                      // INDICE PER L'ARRAY WORDS
  int drop = 0;                       // COUNTER DELLE GOCCE E DELLE PAUSE
  int oldCheck = 50;                  // VECCHIO VALORE
  int newCheck;                       // NUOVO VALORE
  //############################################################################
  while(true) {
    if (digitalRead(6) == true) {                           // SE C'È ACQUA INIZIA
      while(true){
        if (digitalRead(6)) newCheck = 1;                   // VALORE CORRENTE
        else newCheck = 0;
        if ((newCheck != oldCheck) && (oldCheck != 50)){
          if (oldCheck == 1) Serial.print("GOCCIA: ");
          else if (oldCheck == 0) Serial.print("PAUSA: ");
          Serial.println(drop);
          if (oldCheck == 1) {                              // SE IL VALORE ERA ACQUA
            if (drop >= 0 && drop < 50) {
              Serial.println("DOT");
              character +=".";
            }
            else if (drop >= 50 && drop < 150) {
              Serial.println("DASH");
              character +="-";
            }
            else {
              Serial.println("END MESSAGE");
              translate(words);                            // QUANDO IL MESSAGGIO FINISCE FACCIO LA TRADUZIONE
            }
          }
          else {                                           // SE IL VALORE ERA PAUSA
            if (drop >= 0 && drop < 50) {
              // NIENTE
            }
            else if (drop >= 50 && drop < 150) {
              Serial.println("CHAR PAUSE");
              words[index] = character;
              index++;
            }
            else {
              Serial.println("WORD PAUSE");
              words[index] = " ";
              index++;
            }
          }
          drop = 0;
        }
        drop++;
        oldCheck = newCheck;
        delay(10);
      }
    }
  }
}

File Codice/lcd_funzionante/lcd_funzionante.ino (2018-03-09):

#include <Wire.h>
#include <LiquidCrystal_PCF8574.h>

LiquidCrystal_PCF8574 lcd(0x27);  // set the LCD address to 0x27 for a 16 chars and 2 line display

int show;

void setup()
{
  int error;

  Serial.begin(115200);
  Serial.println("LCD...");

  while (! Serial);

  Serial.println("Dose: check for LCD");

  // See http://playground.arduino.cc/Main/I2cScanner
  Wire.begin();
  Wire.beginTransmission(0x27);
  error = Wire.endTransmission();
  Serial.print("Error: ");
  Serial.print(error);

  if (error == 0) {
    Serial.println(": LCD found.");

  } else {
    Serial.println(": LCD not found.");
  } // if

  lcd.begin(16, 2);         //Inizializza il display lcd
  lcd.setBacklight(255);    //Accende la luce del display
  show = 0;
} // setup()

void loop()
{
  lcd.print("Ciao!!!");     //Stampa sul display la stringa "Ciao!!!"
  delay(2000);
  lcd.clear();              //Ripulisce il display
 /* if (show == 0) {
    lcd.setBacklight(255);
    lcd.home(); lcd.clear();
    lcd.print("Hello LCD");
    delay(1000);

    lcd.setBacklight(0);
    delay(400);
    lcd.setBacklight(255);

  } else if (show == 1) {
    lcd.clear();
    lcd.print("Cursor On");
    lcd.cursor();

  } else if (show == 2) {
    lcd.clear();
    lcd.print("Cursor Blink");
    lcd.blink();

  } else if (show == 3) {
    lcd.clear();
    lcd.print("Cursor OFF");
    lcd.noBlink();
    lcd.noCursor();

  } else if (show == 4) {
    lcd.clear();
    lcd.print("Display Off");
    lcd.noDisplay();

  } else if (show == 5) {
    lcd.clear();
    lcd.print("Display On");
    lcd.display();

  } else if (show == 7) {
    lcd.clear();
    lcd.setCursor(0, 0);
    lcd.print("*** first line.");
    lcd.setCursor(0, 1);
    lcd.print("*** second line.");

  } else if (show == 8) {
    lcd.scrollDisplayLeft();
  } else if (show == 9) {
    lcd.scrollDisplayLeft();
  } else if (show == 10) {
    lcd.scrollDisplayLeft();
  } else if (show == 11) {
    lcd.scrollDisplayRight();
  } // if

  delay(2000);
  show = (show + 1) % 12;*/
} // loop()

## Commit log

2017-12-01 Analisi dei costi
    [Analisi Costi.xlsx]
2017-12-15 Analisi Costi
    [Analisi Costi.xlsx]
2017-12-15 Diario lezione scorsa pdf e diario di questa settimana
2017-12-22 Modifica di diversi capitoli della doc
2017-12-22 Progetto grafico
    [ProgettoGraficoDavide.skp]
2018-01-26 Riordinamento e modifica readme
    [Analisi Costi.xlsx]
2018-01-26 Schema elettrico
    [Schema elettrico.fzz]
2018-01-26 Gantt consuntivo di oggi
2018-02-09 Diario di oggi
2018-02-23 Aggiunta diarioe modifica codice Arduino
2018-03-09 Arduino Leonardo
2018-03-09 Cartella Fritzing aggiunta
    [Montaggio IR.fzz]
2018-03-09 Fritzing LCD
    [Arduino_Uno_i2C_LCD.fzz]
2018-03-09 Eliminazione Cartella
    [Schema elettrico.fzz]
2018-03-09 Codice sensore+pompa
